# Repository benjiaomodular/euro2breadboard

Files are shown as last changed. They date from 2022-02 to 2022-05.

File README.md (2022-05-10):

# euro2breadboard

A simple breadboard power adapter for Eurorack module development.

## Versions
### v1.1 Quick fixes
- Spacing of power rail pins was fixed.
- Updated footprint of toggle switch. Made the drill holes a bit wider.
- Switched the position of the toggle and the LEDs so you can see the lights better.

### v1.0 Initial design
- Power rails work great.
- Holes of toggle switch were a bit too tight.
- Spacing of outer pins off with actual breadboard power rails. Can be resolved by soldering while installed on breadboard.

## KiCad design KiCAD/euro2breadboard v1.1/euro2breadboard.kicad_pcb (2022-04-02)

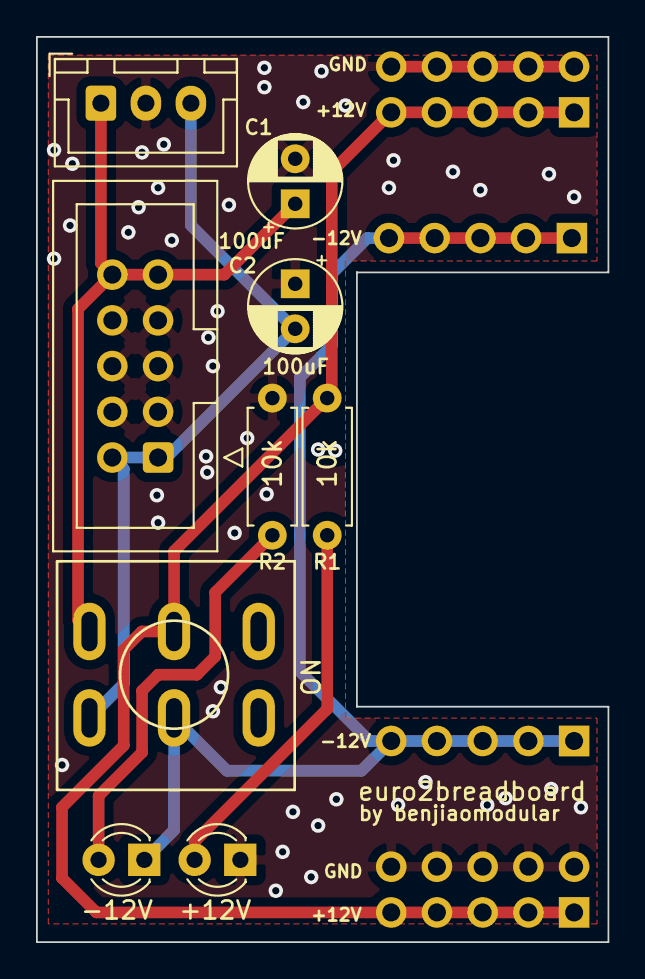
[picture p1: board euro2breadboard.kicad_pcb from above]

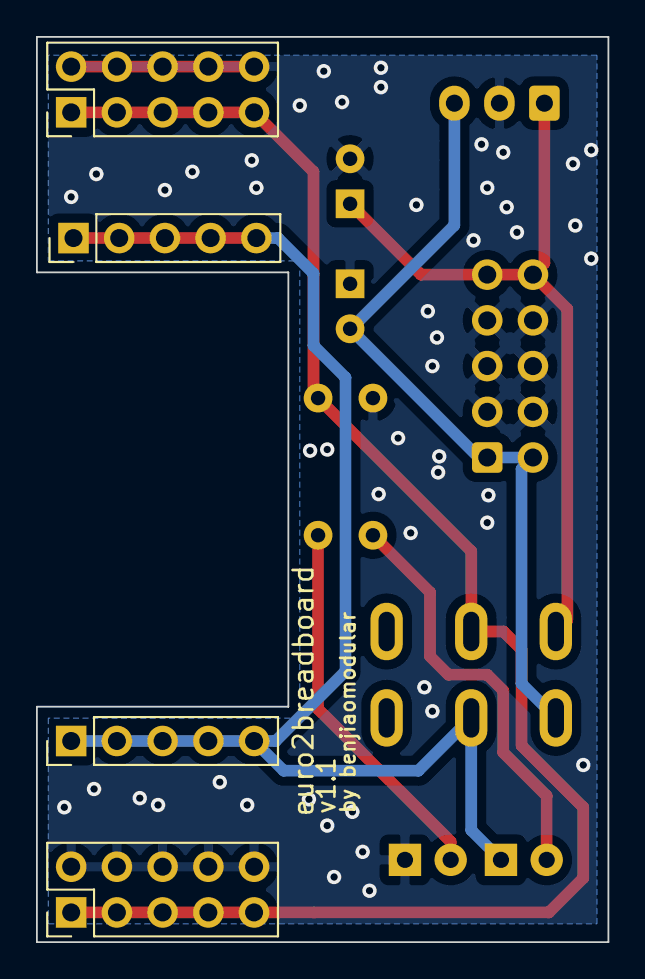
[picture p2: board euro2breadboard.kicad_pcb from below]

Board: 2 copper layers, 31.8 x 50.3 mm, 13 parts (4 on the bottom side), 7 nets.

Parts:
+12V: LED; LED_D3.0mm
-12V: LED; LED_D3.0mm
BB_POWER_PINS1, BB_POWER_PINS2: Conn_02x05_Odd_Even; PinHeader_2x05_P2.54mm_Vertical
C1, C2: 100uF; CP_Radial_D5.0mm_P2.50mm
J1: JST_BUS; JST_XH_B3B-XH-A_1x03_P2.50mm_Vertical
J2: IDC_BUS; IDC-Header_2x05_P2.54mm_Vertical
NEG_12V_PINS1, NEG_12V_PINS2: Conn_01x05_Male; PinHeader_1x05_P2.54mm_Vertical
R1, R2: 10k; Resistor_L6.3mm_D2.5mm_P7.62mm_Horizontal
SW1: SW_DPDT_x2; ToggleSwitch_MTS-202_DPDT

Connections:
+12V: C1.1, J1.1, J2.9, J2.10, SW1.3
-12V: C2.2, J1.3, J2.1, J2.2, SW1.6
GND: +12V.1, BB_POWER_PINS1.2, BB_POWER_PINS1.4, BB_POWER_PINS1.6, BB_POWER_PINS1.8, BB_POWER_PINS1.10, BB_POWER_PINS2.2, BB_POWER_PINS2.4, BB_POWER_PINS2.6, BB_POWER_PINS2.8, BB_POWER_PINS2.10, C1.2, C2.1, J1.2, J2.3, J2.4, J2.5, J2.6, J2.7, J2.8, R2.2
unnamed: BB_POWER_PINS1.1, BB_POWER_PINS1.3, BB_POWER_PINS1.5, BB_POWER_PINS1.7, BB_POWER_PINS1.9, BB_POWER_PINS2.1, BB_POWER_PINS2.3, BB_POWER_PINS2.5, BB_POWER_PINS2.7, BB_POWER_PINS2.9, R1.2, SW1.2
unnamed: -12V.1, NEG_12V_PINS1.1, NEG_12V_PINS1.2, NEG_12V_PINS1.3, NEG_12V_PINS1.4, NEG_12V_PINS1.5, NEG_12V_PINS2.1, NEG_12V_PINS2.2, NEG_12V_PINS2.3, NEG_12V_PINS2.4, NEG_12V_PINS2.5, SW1.5
unnamed: -12V.2, R2.1
unnamed: +12V.2, R1.1

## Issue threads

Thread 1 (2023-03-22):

Some breadboards are not compatible with the -12V pins

benjiao, 2023-03-22:
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

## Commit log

2022-02-06 Fixed board dimensions
    [euro2breadboard-B_Cu.gbr, euro2breadboard-B_Mask.gbr, euro2breadboard-B_Paste.gbr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]
2022-02-19 Added v1.1 layout
    [euro2breadboard.kicad_pcb, euro2breadboard.sch]
2022-02-19 Added gerber files
    [euro2breadboard-B_Cu.gbr, euro2breadboard-B_Mask.gbr, euro2breadboard-B_Paste.gbr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]
2022-04-02 more layout tweaks
    [euro2breadboard.kicad_pcb]
